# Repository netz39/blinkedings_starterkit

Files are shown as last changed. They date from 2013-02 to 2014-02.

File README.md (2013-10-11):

# Starterkit

## v1

Erste Version für den Tag der offenen Tür im März 2013 und für den *AVR 101* Workshop auf der OHM2013.

### Teileliste
* USB-Buchse: USB BW
  * alternative (Stecker): USB AG-KV
* LED (smd): LRTB G6TG
  * alternative: LED RGB5 DIFFUS
* ATTiny: ATiny 85-20 PU
* LM2940 (Spannungsregler): LM 2940 CT5
* Kondensatoren:
  * Ladekondensator(>=22μF, elko): RAD FC 47/25
  * 2 * 100nF: Z5U-2,5 100N
* Platinen: BEL 160X100-1

CC-BY-SA 2.0 24367dfa & bastinat0r @ netz39
-- no military use --

## v2.x
Complete new design started at OHM2013 …

### Part List
* see our [Wiki](http://www.netz39.de/wiki/projects:2013:avr_starterkit#teile1)

### License
mood39 aka Starterkit v2.x von Netz39 e.V. is licensed under the [Creative Commons Attribution-ShareAlike 3.0 Unported License]( http://creativecommons.org/licenses/by-sa/3.0/).

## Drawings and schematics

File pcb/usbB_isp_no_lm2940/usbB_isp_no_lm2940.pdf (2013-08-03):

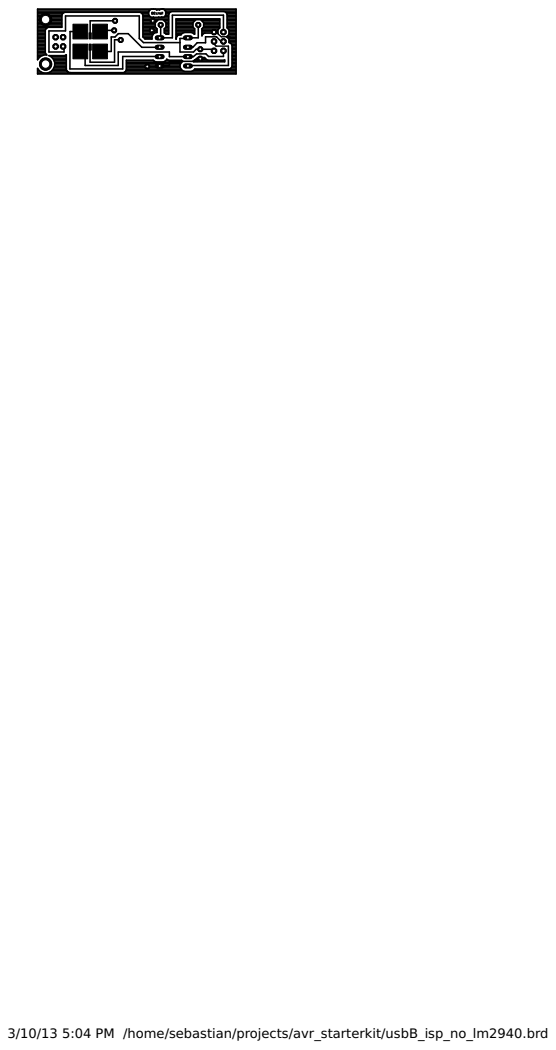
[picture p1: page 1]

3/10/13 5:04 PM /home/sebastian/projects/avr_starterkit/usbB_isp_no_lm2940.brd

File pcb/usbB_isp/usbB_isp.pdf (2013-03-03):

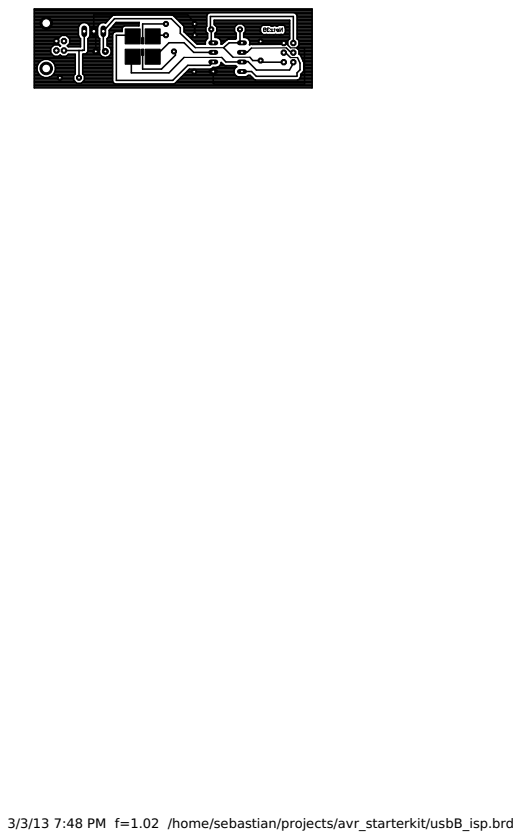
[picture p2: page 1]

3/3/13 7:48 PM f=1.02 /home/sebastian/projects/avr_starterkit/usbB_isp.brd

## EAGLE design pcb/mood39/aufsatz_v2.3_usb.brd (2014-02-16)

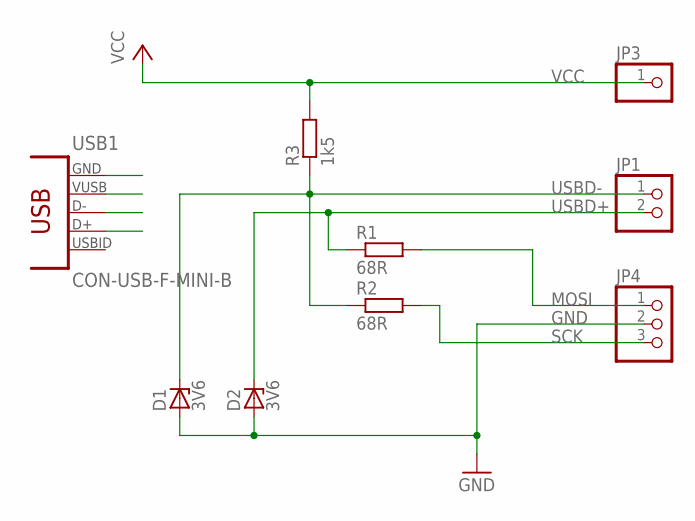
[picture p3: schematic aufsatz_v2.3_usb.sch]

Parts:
D1, D2: 3V6; SOD80C
JP1: PINHD-1X2; 1X02
JP3: PINHD-1X1; 1X01
JP4: PINHD-1X3; 1X03
R1, R2: 68R; R0805
R3: 1k5; R0805
USB1: CON-USB-F-MINI-B; CONN_USB_MINI-B

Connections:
GND: D1.A, D2.A, JP4.2, USB1.GND
MOSI: JP4.1, R1.2
SCK: JP4.3, R2.2
USBD+: D2.C, JP1.2, R1.1, USB1.D+
USBD-: D1.C, JP1.1, R2.1, R3.1, USB1.D-
VCC: JP3.1, R3.2, USB1.VUSB

Board: 2 copper layers, 9 parts (0 on the bottom side), 6 nets, no tracks yet.

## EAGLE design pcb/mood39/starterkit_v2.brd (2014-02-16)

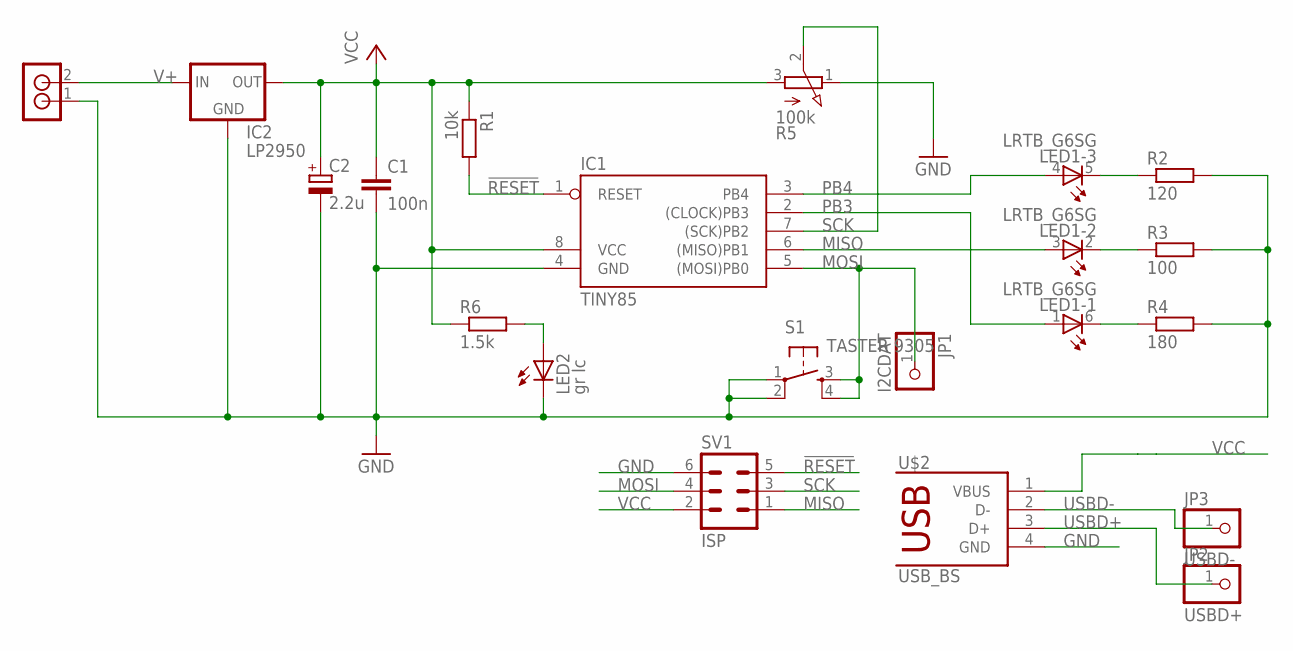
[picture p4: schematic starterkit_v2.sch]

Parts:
C1: 100n; C0805
C2: 2.2u; E2-5
IC1: TINY85; DIL08
IC2: LP2950; TO92
JP1: I2CDAT; 1X01
JP2: USBD+; 1X01
JP3: USBD-; 1X01
LED1: LRTB_G6SG
LED2: gr lc; LED3MM
R1: 10k; R0805
R2: 120; R0805
R3: 100; R0805
R4: 180; R0805
R5: 100k; ALPS_RK09K113
R6: 1.5k; R0805
S1: TASTER 9305; JTP-1130
SV1: ISP; ML6
U$1: RIACON_101_2
U$2: USB_BS; USB_B_UP-S

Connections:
!RESET: IC1.1 (RESET), R1.2, SV1.5
GND: C1.2, C2.-, IC1.4 (GND), IC2.2 (GND), LED2.K (C), R2.2, R3.2, R4.2, R5.1 (E), S1.1, S1.2 (P1), SV1.6, U$1.1, U$2.4 (GND)
MISO: IC1.6 ((MISO)PB1), LED1.3 (A), SV1.1
MOSI: IC1.5 ((MOSI)PB0), JP1.1, S1.3 (S), S1.4 (S1), SV1.4
unnamed: LED2.A, R6.2
unnamed: LED1.5 (C), R2.1
unnamed: LED1.2 (C), R3.1
unnamed: LED1.6 (C), R4.1
PB3: IC1.2 ((CLOCK)PB3), LED1.1 (A)
PB4: IC1.3 (PB4), LED1.4 (A)
SCK: IC1.7 ((SCK)PB2), R5.2 (S), SV1.3
USBD+: JP2.1, U$2.3 (D+)
USBD-: JP3.1, U$2.2 (D-)
V+: IC2.3 (IN), U$1.2
VCC: C1.1, C2.+, IC1.8 (VCC), IC2.1 (OUT), R1.1, R5.3 (A), R6.1, SV1.2, U$2.1 (VBUS)

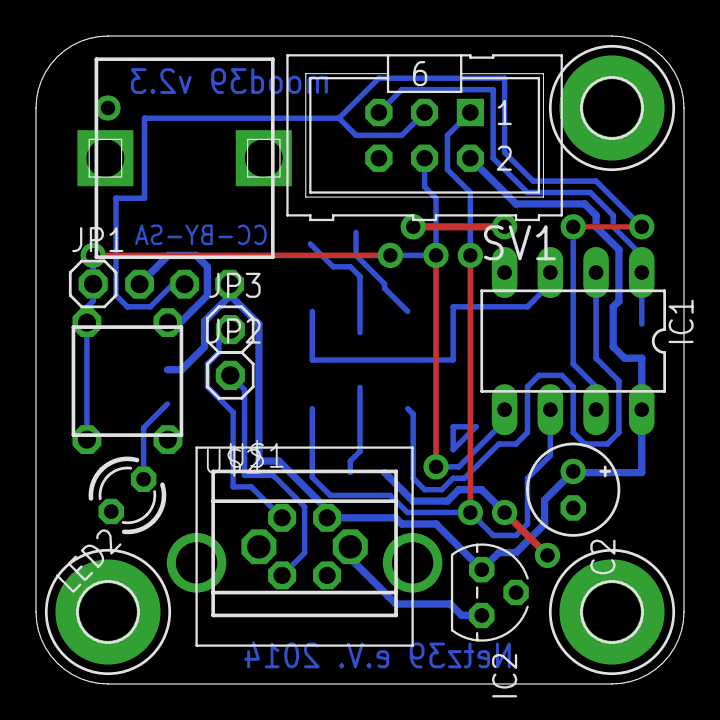
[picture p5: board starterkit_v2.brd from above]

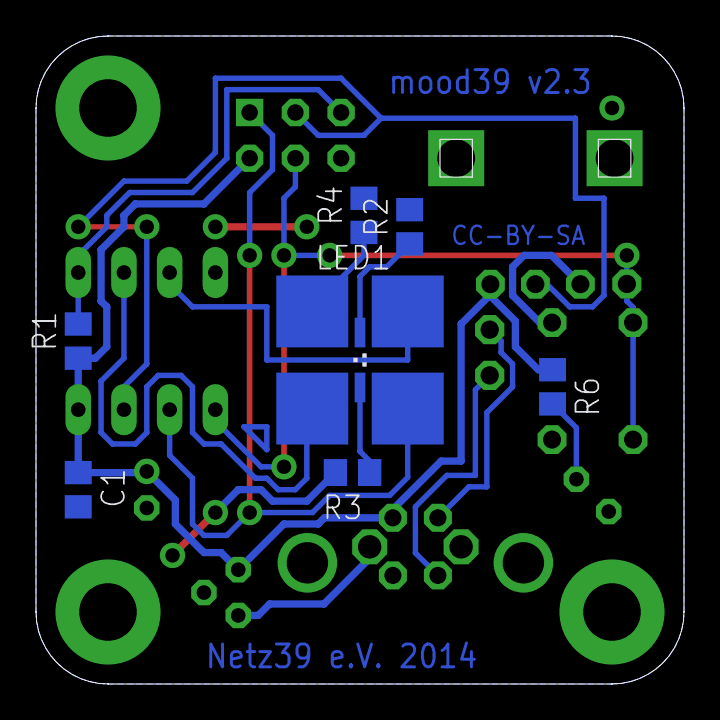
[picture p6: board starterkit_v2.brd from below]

Board: 2 copper layers, 36.0 x 36.0 mm, 22 parts (7 on the bottom side), 15 nets.

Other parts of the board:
U$4, U$5, U$6: 3,2-PAD

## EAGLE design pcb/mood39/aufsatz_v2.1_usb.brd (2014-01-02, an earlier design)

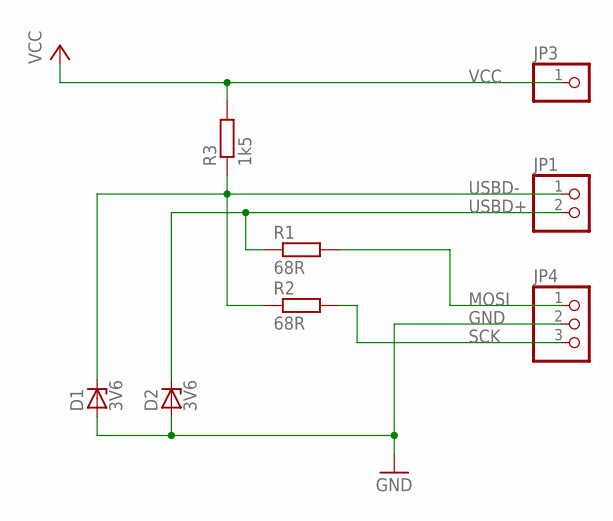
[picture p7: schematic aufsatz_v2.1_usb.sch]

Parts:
D1, D2: 3V6; SOD80C
JP1: PINHD-1X2; 1X02
JP3: PINHD-1X1; 1X01
JP4: PINHD-1X3; 1X03
R1, R2: 68R; R0805
R3: 1k5; R0805

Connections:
GND: D1.A, D2.A, JP4.2
MOSI: JP4.1, R1.2
SCK: JP4.3, R2.2
USBD+: D2.C, JP1.2, R1.1
USBD-: D1.C, JP1.1, R2.1, R3.1
VCC: JP3.1, R3.2

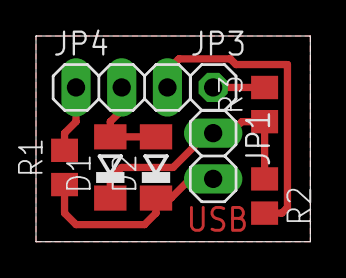
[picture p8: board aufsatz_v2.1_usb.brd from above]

Board: 2 copper layers, 15.2 x 11.4 mm, 8 parts (0 on the bottom side), 6 nets.

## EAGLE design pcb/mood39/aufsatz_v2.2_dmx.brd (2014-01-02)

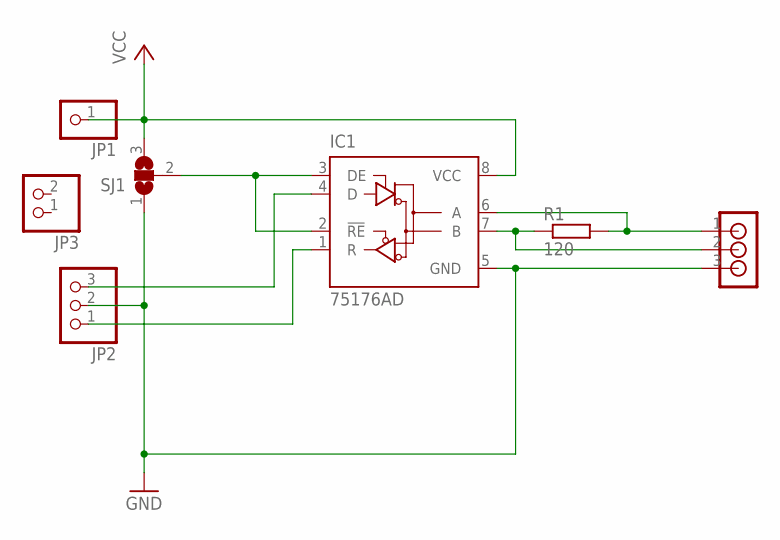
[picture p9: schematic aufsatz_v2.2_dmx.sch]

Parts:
IC1: 75176AD; D_R-PDSO-G8
JP1: PINHD-1X1; 1X01
JP2: PINHD-1X3; 1X03
JP3: PINHD-1X2; 1X02
R1: 120; R0805
SJ1: SJ2W; SJ_2
U$1: RIACON_59_3

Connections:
A: IC1.6 (A), R1.2, U$1.1
B: IC1.7 (B), R1.1, U$1.2
D: IC1.4 (D), JP2.3
GND: IC1.5 (GND), JP2.2, SJ1.1, U$1.3
unnamed: IC1.2 (!RE), IC1.3 (DE), SJ1.2
R: IC1.1 (R), JP2.1
VCC: IC1.8 (VCC), JP1.1, SJ1.3

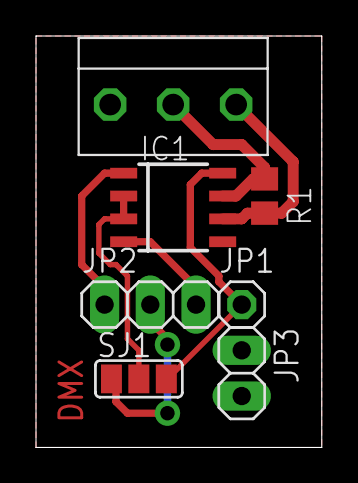
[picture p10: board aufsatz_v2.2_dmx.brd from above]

Board: 2 copper layers, 15.9 x 22.9 mm, 7 parts (0 on the bottom side), 7 nets.

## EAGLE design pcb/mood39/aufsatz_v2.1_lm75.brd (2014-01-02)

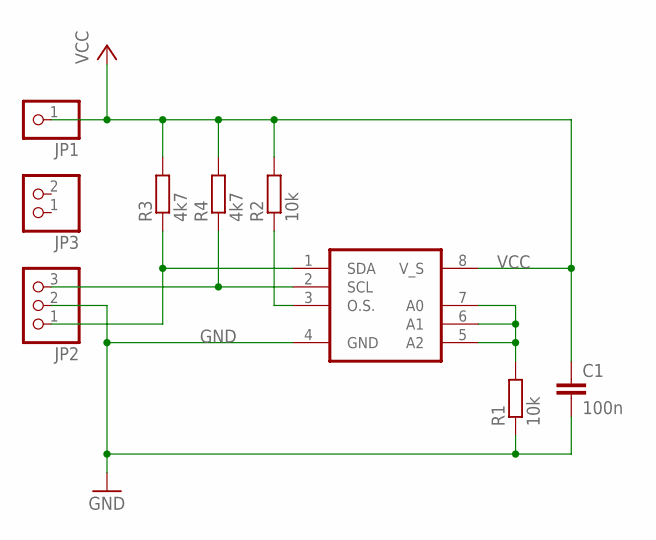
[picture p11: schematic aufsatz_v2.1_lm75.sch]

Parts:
C1: 100n; C0805
JP1: PINHD-1X1; 1X01
JP2: PINHD-1X3; 1X03
JP3: PINHD-1X2; 1X02
R1: 10k; R0805
R2: 10k; 0204/5
R3: 4k7; 0204/7
R4: 4k7; R0805
U$1: LM75; SOIC8

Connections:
GND: C1.2, JP2.2, R1.1, U$1.4 (GND)
unnamed: R1.2, U$1.5 (A2), U$1.6 (A1), U$1.7 (A0)
unnamed: R2.1, U$1.3 (O.S.)
SCL: JP2.3, R4.1, U$1.2 (SCL)
SDA: JP2.1, R3.1, U$1.1 (SDA)
VCC: C1.1, JP1.1, R2.2, R3.2, R4.2, U$1.8 (V_S)

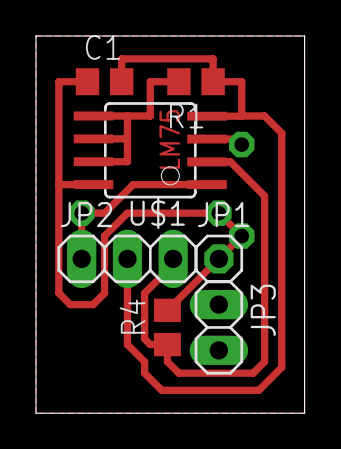
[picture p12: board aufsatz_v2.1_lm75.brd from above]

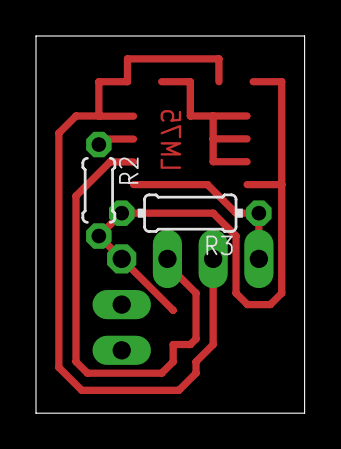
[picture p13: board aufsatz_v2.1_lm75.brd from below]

Board: 2 copper layers, 14.9 x 21.0 mm, 9 parts (2 on the bottom side), 6 nets.

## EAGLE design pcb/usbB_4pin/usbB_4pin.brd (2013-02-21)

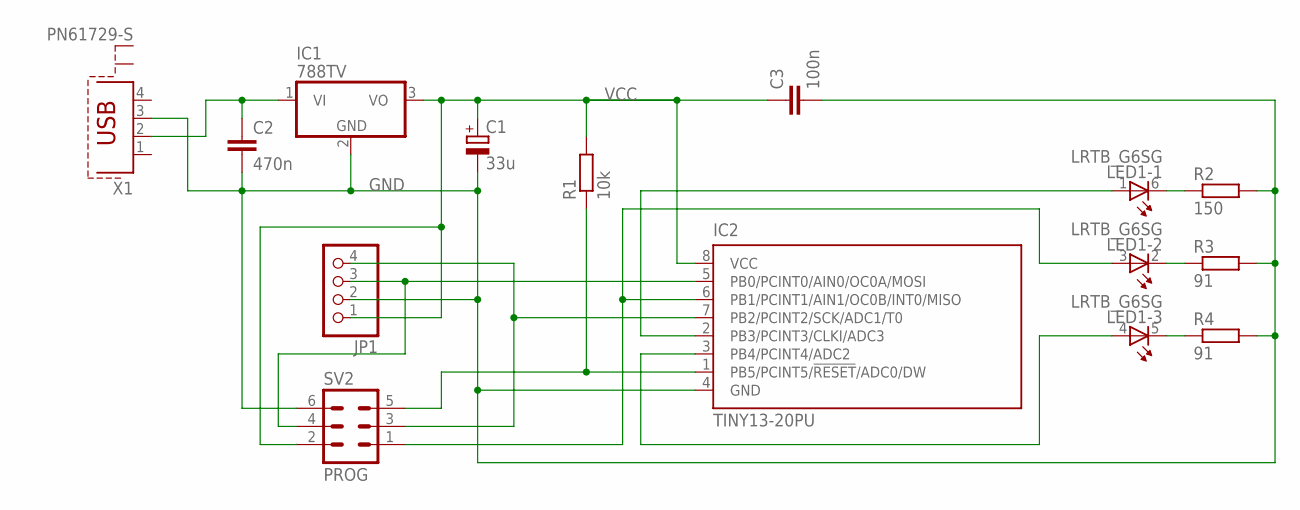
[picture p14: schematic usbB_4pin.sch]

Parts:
C1: 33u; E2,5-6E
C2: 470n; C050-025X075
C3: 100n; C050-025X075
IC1: 788TV; TO220V
IC2: TINY13-20PU; DIL08
JP1: PINHD-1X4; 1X04
LED1: LRTB_G6SG
R1: 10k; 0204/7
R2: 150; 0204/7
R3, R4: 91; 0204/7
SV2: PROG; ML6
X1: PN61729-S

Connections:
GND: C1.-, C2.2, C3.2, IC1.2 (GND), IC2.4 (GND), JP1.2, R2.2, R3.2, R4.2, SV2.6, X1.3
MISO: IC2.6 (PB1/PCINT1/AIN1/OC0B/INT0/MISO), LED1.3 (A), SV2.1
unnamed: C2.1, IC1.1 (VI), X1.2
unnamed: IC2.2 (PB3/PCINT3/CLKI/ADC3), LED1.1 (A)
unnamed: LED1.5 (C), R4.1
unnamed: LED1.2 (C), R3.1
unnamed: LED1.6 (C), R2.1
unnamed: IC2.3 (PB4/PCINT4/ADC2), LED1.4 (A)
unnamed: IC2.5 (PB0/PCINT0/AIN0/OC0A/MOSI), JP1.3, SV2.4
SCK: IC2.7 (PB2/PCINT2/SCK/ADC1/T0), JP1.4, SV2.3
VCC: C1.+, C3.1, IC1.3 (VO), IC2.8 (VCC), JP1.1, R1.2, SV2.2
_RESET: IC2.1 (PB5/PCINT5/!RESET!/ADC0/DW), R1.1, SV2.5


Board: 2 copper layers, 100.0 x 80.0 mm, 13 parts (1 on the bottom side), 12 nets.

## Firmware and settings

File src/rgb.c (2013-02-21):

#include <avr/io.h>
#include <avr/interrupt.h>


#define F_CPU					8000000UL
#include <util/delay.h>

#define fucking				unsigned
#define MAX_INTERVAL	128
#define WAIT_MS				1

#define PIN_RED 0x02
#define PIN_GREEN 0x08
#define PIN_BLUE 0x10

#define PORT_MASK (PIN_RED | PIN_GREEN | PIN_BLUE)

/* globals */
volatile fucking char comp_R, comp_G, comp_B;
volatile fucking char timer_overflow_count = 0;
volatile fucking char pin_level = 0x00;

volatile fucking char rng_x = 37;
volatile fucking char rng_a = 5;
volatile fucking char rng_c = 51;

const unsigned char pwmtable[32] = { 0, 1, 2, 3, 4, 6, 7, 9, 10, 12, 13, 15, 17, 19, 21, 23, 25, 27, 30, 33, 36, 39, 42, 46, 51, 56, 61, 68, 76, 87, 102, 128 };

/* ISR */
ISR( TIMER0_OVF_vect )
{

	PORTB = pin_level & PORT_MASK;
	timer_overflow_count = (timer_overflow_count + 1) % MAX_INTERVAL;
	
	if(timer_overflow_count < comp_R) {
		pin_level |= PIN_RED;
	} else {
		pin_level &= ~PIN_RED;
	}
	
	if((timer_overflow_count + MAX_INTERVAL / 3) % MAX_INTERVAL < comp_G) {
		pin_level |= PIN_GREEN;
	} else {
		pin_level &= ~PIN_GREEN;
	}

	
	if((timer_overflow_count + MAX_INTERVAL / 3 * 2) % MAX_INTERVAL < comp_B) {
		pin_level |= PIN_BLUE;
	} else {
		pin_level &= ~PIN_BLUE;
	}

}

/* initialisation */
void init( void )
{
	cli();
	
	/* clock prescaler */
	CLKPR = (1 << CLKPCE);
	CLKPR = 0;

	/* enable output ports */
	DDRB = PORT_MASK;
	PORTB = 0x00 & (PORTB | ~PORT_MASK);

	/* timer init */
	TIFR &= ~(1 << TOV0);
	TIMSK |= (1 << TOIE0);

	TCCR0B = (TCCR0B & 0xF8) | (0x01 & 0x07);

	sei();

	comp_R = 10;
	comp_G = 10;
	comp_B = 10;
}

/* set the color to RGB-Value */
void set_RGB( fucking char r, fucking char g, fucking char b )
{
	comp_R = pwmtable[ r >> 3 ];
	comp_G = pwmtable[ g >> 3 ];
	comp_B = pwmtable[ b >> 3 ];
}

/* create new random number with acm-method*/
fucking char random() {
	
	rng_x = ((rng_x * rng_a) + rng_c) % 256;
	return rng_x;

}

/* fade from color 1 to color 2 in n easy steps ... */
void fade_color(fucking char r1, fucking char g1, fucking char b1, fucking char r2, fucking char g2, fucking char b2, fucking char range) {
	fucking char i = 0;
	while(i++ < range) {
		_delay_ms(WAIT_MS);
		set_RGB((r1 + (r2 - r1) * i / 255) , (g1 + (g2 - g1) * i / 255), (b1 + (b2 - b1) * i / 255));
	}
}

/* compute rgb-value from hsv-colospace */
void h_to_rgb(fucking char h, fucking char *r, fucking char *g, fucking char *b) {
	if ( h <= 42 ) {
		*r = 255;
		*g = h * 6;
		*b = 0;
	} else if ( h > 42 && h <= 85 ) {
		*r = (85 - h) * 6;
		*g = 255;
		*b = 0;
	} else if ( h > 85 && h <= 127 ) {
		*r = 0;
		*g = 255;
		*b = (h - 85) * 6;
	} else if ( h > 127 && h <= 170 ) {
		*r = 0;
		*g = (170 - h) * 6;
		*b = 255;
	} else if ( h > 170 && h <= 212 ) {
		*r = (h - 170) * 6;
		*g = 0;
		*b = 255;
	} else {
		*r = 255;
		*g = 0;
		*b = (255 - h) * 6;
	}
}

/* set led to specific hsv-value (h, 255, 255) */
void set_hsv(fucking char h) {
	fucking char r;
	fucking char g;
	fucking char b;
	h_to_rgb(h, &r, &g, &b);
	set_RGB(r, g, b);
}

/* 
 * different demo-shows 
 *
 * 0: random h in hsv-space
 * 1: cycle h in hsv-space
 * 2: random rgb-values
 * 3 aka default: flash each combination of RGB
 */
void demoLoop( char type ) {

	fucking char r = 0;
	fucking char g = 0;
	fucking char b = 0;

	fucking char nr = 0;
	fucking char ng = 0;
	fucking char nb = 0;
	

  char num = 16;
	while(num > 0) {
		num--;
		switch ( type ) {
			case 0:
				h_to_rgb(random(), &nr, &ng, &nb);
				break;
			case 1:
				h_to_rgb(num * 16, &nr, &ng, &nb);
				break;
			case 2:
				nr = random();
				ng = random();
				nb = random();
				break;
			case 3:
				if((num & 8) > 0) {
					nr = 255;
				} else {
					nr = 0;
				}
				if((num & 4) > 0) {
					ng = 255;
				} else {
					ng = 0;
				}
				if((num & 2) > 0) {
					nb = 255;
				} else {
					nb = 0;
				}
				if((num & 1) == 0) {
					nr = 0;
					ng = 0;
					nb = 0;
				}
				break;
			default:
				h_to_rgb(random(), &nr, &ng, &nb);
		}
		fade_color(r, g, b, nr, ng, nb, 255);
		
		r = nr;
		g = ng;
		b = nb;
	}
}

int main( void ) 
{	
	init();
	while(1) {
		for(fucking char type = 0; type < 4; type++) {
			demoLoop(type);
			set_RGB(0,0,0);
			_delay_ms(WAIT_MS * 1000);
		}
	}
}

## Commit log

2013-02-19 initial board revision
    [usbB_4pin.brd, usbB_4pin.sch]
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2013-02-19 minor layout changes
    [usbB_4pin.brd, usbB_4pin.sch]
2013-02-20 correct values
    [usbB_4pin.brd, usbB_4pin.sch]
2013-02-20 correct pin headers ftw
    [usbB_4pin.brd, usbB_4pin.sch]
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2013-03-02 isp for b4st1n4t0r
    [usbB_isp.brd, usbB_isp.sch]
2013-03-03 fixing some errors i.e. width
    [usbB_isp.brd, usbB_isp.sch]
2013-03-03 fixing mass pin
    [usbB_isp.brd, usbB_isp.sch]
2013-03-03 fixing usb-pin GND
    [usbB_isp.brd, usbB_isp.sch]
2013-03-03 fixing usb-pins
    [usbB_isp.brd, usbB_isp.sch]
2013-03-04 adapted design rules, not DRC done yet
    [usbB_isp.brd]
2013-03-04 better GND connection
    [usbB_isp.brd]
2013-03-09 done stuff
    [usbB_isp.brd, usbB_isp.sch]
2013-03-09 adding version without lm2940
    [usbB_isp_no_lm2940.brd, usbB_isp_no_lm2940.sch]
2013-03-10 moving some wire
    [usbB_isp_no_lm2940.brd]
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2013-03-10 waste less space when printing
    [usbB_isp_no_lm2940.brd]
2013-03-10 adjusting writing
    [usbB_isp_no_lm2940.brd]
2013-03-10 minor adjustments (tm)
    [usbB_isp_no_lm2940.brd, usbB_isp_no_lm2940.sch]
2013-03-13 wrong usb-pin *again and again and again and again …
    [usbB_isp_no_lm2940.brd, usbB_isp_no_lm2940.sch]
2013-08-03 some structure
    [usbB_4pin.brd, usbB_4pin.sch, usbB_isp.brd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]
2013-08-03 add new eagle project
    [starterkit_v2.sch]
2013-08-03 basic circuit with uC and LED
    [starterkit_v2.sch]
2013-08-03 add some connectors and the voltage regulator
    [starterkit_v2.sch]
2013-08-04 add board (not routed) and design rules
    [starterkit_v2.brd, starterkit_v2.sch]
2013-08-04 start routing
    [starterkit_v2.brd, starterkit_v2.sch]
2013-08-04 commit before battery low
    [starterkit_v2.brd, starterkit_v2.sch]
2013-08-05 routing to a point where the right packages are needed
    [starterkit_v2.brd, starterkit_v2.sch]
2013-08-06 der miniaturtaster ist arg groß
    [starterkit_v2.brd, starterkit_v2.sch]
2013-08-07 teile ersetzt durch tatsächlich verfügbare
    [starterkit_v2.brd, starterkit_v2.sch]
2013-08-07 Taster ersetzt
    [starterkit_v2.brd, starterkit_v2.sch]
2013-08-08 add pins for USB data
    those pins can be used for actually accessing the avr via USB, but it
    needs some additional circuit stacked on the pin headers
    [starterkit_v2.brd, starterkit_v2.sch]
2013-08-12 replaced USB connector
    [starterkit_v2.brd, starterkit_v2.sch]
2013-08-15 proceed routing (this will be fun)
    [starterkit_v2.brd]
2013-08-16 replace voltage regulator
    this saves one capacitor and lots of space
    [starterkit_v2.brd, starterkit_v2.sch]
2013-08-23 proceed routing, still not ready
    [starterkit_v2.brd]
2013-08-26 routing almost done
    [starterkit_v2.brd, starterkit_v2.sch]
2013-08-26 move vias
    [starterkit_v2.brd]
2013-08-27 routing improved
    after ERC and DRC
    [starterkit_v2.brd, starterkit_v2.sch]
2013-08-27 text und marker
    [starterkit_v2.brd]
2013-08-27 connect GND
    we could give this a try
    [starterkit_v2.brd]
2013-08-29 letzte Änderungen vor'm Ätzen
    [starterkit_v2.brd]
2013-09-04 move uC to top layer
    [starterkit_v2.brd]
2013-09-06 try another puzzle
    [starterkit_v2.brd]
2013-09-06 new usb connector package
    this will be puzzling not fun :-/
    [starterkit_v2.brd, starterkit_v2.sch]
2013-10-08 proceed routing, hopefully not a dead end
    [starterkit_v2.brd]
2013-10-08 still two problems, looks like a dead end
    [starterkit_v2.brd]
2013-10-08 no real improvement, this seemed more promising
    [starterkit_v2.brd]
2013-10-10 reduced to one problem, looks like a dead end
    [starterkit_v2.brd, starterkit_v2.sch]
2013-10-10 connect last signals
    no dead end, phew …
    [starterkit_v2.brd]
2013-10-10 optimize positions
    (no DRC yet)
    [starterkit_v2.brd]
2013-10-10 DRC done
    [starterkit_v2.brd]
2013-10-11 usb aufsatz
    [aufsatz_v2.1_usb.brd, aufsatz_v2.1_usb.sch, starterkit_v2.brd]
2013-10-11 adapt resitor values and add git ignore list
    [starterkit_v2.brd, starterkit_v2.sch]
2013-10-11 value for potentiometer
    [starterkit_v2.brd, starterkit_v2.sch]
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2013-10-12 add I²C temp sensor extension board
    [aufsatz_v2.1_lm75.brd, aufsatz_v2.1_lm75.sch]
2013-10-13 optimize usb add-on board
    [aufsatz_v2.1_usb.brd]
2013-11-08 start optimizing for v2.2
    prevent short circuit
    [starterkit_v2.brd]
2013-11-16 neues Board, alles bisschen auseinander
    [starterkit_v2.brd, starterkit_v2.sch]
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2013-11-17 change text on board
    [starterkit_v2.brd]
2013-11-18 a little space for a tiny logo
    [aufsatz_v2.1_lm75.brd]
2013-11-18 add little LED orientation hint
    [starterkit_v2.brd]
2013-11-21 round corners on gnd polygon
    [starterkit_v2.brd]
2013-12-05 optimize vias
    removed double vias, moved some signals, did DRC again
    [starterkit_v2.brd]
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2014-01-01 square pad for ISP pin 1 and add documentation
    [starterkit_v2.brd, starterkit_v2.sch]
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2014-01-02 add DMX addon board
    [aufsatz_v2.2_dmx.brd, aufsatz_v2.2_dmx.sch]
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2014-01-10 add old v2.0 from adafruit
    [usbtinyisp v2.0.brd, usbtinyisp v2.0.sch]
2014-01-10 started reworking for single layer board
    [usbtinyisp_single.brd, usbtinyisp_single.sch]
2014-01-10 update dimensions and change some packages
    [usbtinyisp_single.brd, usbtinyisp_single.sch]
2014-01-13 vergessene Änderungen
    wenn man nicht alles gleich commited :-/
    [usbtinyisp_single.brd, usbtinyisp_single.sch]
2014-01-13 move mounting holes inward
    [usbtinyisp_single.brd]
2014-01-13 replace mounting pads
    [usbtinyisp_single.brd]
2014-01-13 swapped some gates and moved all parts around
    [usbtinyisp_single.brd, usbtinyisp_single.sch]
2014-01-14 routed
    ready for soldering (first test)
    [usbtinyisp_single.brd, usbtinyisp_single.sch]
2014-01-14 add text, license, and readme
    [usbtinyisp_single.brd]
2014-01-14 swap LED1 with resistor
    [usbtinyisp_single.brd, usbtinyisp_single.sch]
2014-01-15 move holes 0.5 mm inward
    this is like dangerousprototypes.com does, I always thought the mounting
    holes were too near to the edges, see
    http://dangerousprototypes.com/docs/Sick_of_Beige_compatible_cases
    [starterkit_v2.brd]
2014-01-15 fix complaints of #11
    [starterkit_v2.brd, starterkit_v2.sch]
2014-01-16 moved to https://github.com/netz39/circuit_boards (fixes #13)
    [usbtinyisp v2.0.brd, usbtinyisp v2.0.sch, usbtinyisp_single.brd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]
2014-01-29 add via for cnc reference and replace mount pads
    Furthermore bump version to v2.3 because we already etched v2.2 and
    changed the board afterwards so e.g. milling some v2.2 is not possible
    with current master anymore. There's still no tag for v2.2 but I guess
    there just won't be any, maybe a branch must be enough for now.
    [starterkit_v2.brd]
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2014-02-16 neues aufsatzboard für USB, nicht fertig
    [aufsatz_v2.3_usb.brd, aufsatz_v2.3_usb.sch]
